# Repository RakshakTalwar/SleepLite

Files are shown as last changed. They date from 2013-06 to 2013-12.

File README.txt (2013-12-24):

This is an open collection of files for the SleepLite to allow the SleepLite to be fully open source and in public domain. 

You are free to use this any way you choose, non-commercial, commercial, or hobby use. 
Please give due credit. 

You can also purchase a kit with all the components, PCB, and preflashed microcontroller
here --> http://www.jameco.com/webapp/wcs/stores/servlet/ProductDisplay?productId=2184157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

Full tutorial with pictures, code, etc. is available 
here --> http://raptorbird.com/sleeplite-kit.php

I invested time and resources into making SleepLite fully open source and accessible, please support me by buying from Jameco or by contacting me for one directly at contact@raptorbird.com.

Written by Rakshak Talwar of RaptorBird.
Fully open source, hack your way to better sleep!

The software, information about hardware, hardware, and any other information here is without warranty. It is your responsibility only. 
This device has not been evaluated by the Food and Drug Administration and is not intended to diagnose, treat, cure or prevent any disease.
Caution: Do not use if you have heart problems or are prone to epileptic seizures.

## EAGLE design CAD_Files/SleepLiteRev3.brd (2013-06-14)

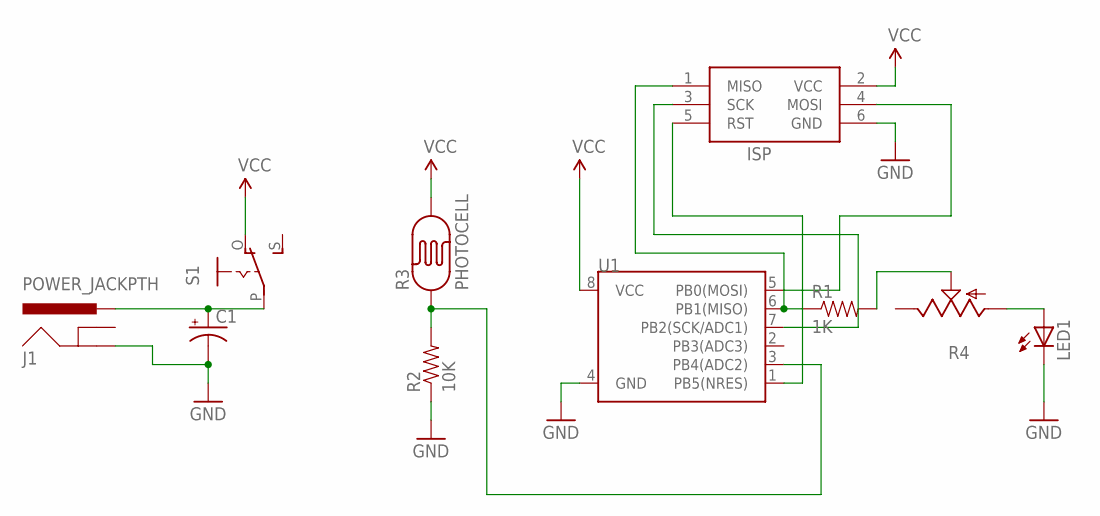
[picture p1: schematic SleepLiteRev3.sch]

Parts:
C1: CAP_POLPTH2; CPOL-RADIAL-10UF-25V
ISP: AVRISP-6; AVRISP
J1: POWER_JACKPTH; POWER_JACK_PTH
LED1: LED5MM
R1: 1K; AXIAL-0.4
R2: 10K; AXIAL-0.4
R3: PHOTOCELL; PHOTOCELL-KIT
R4: TRIM_US-B64Y; B64Y
S1: EG1218S; EG1218
U1: ATTINY13DIP; DIP08

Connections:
GND: C1.2 (-), ISP.6 (GND), J1.GND, LED1.K (C), R2.P$1 (1), U1.4 (GND)
unnamed: C1.1 (+), J1.PWR, S1.P
unnamed: R2.P$2 (2), R3.1, U1.3 (PB4(ADC2))
unnamed: ISP.1 (MISO), R1.P$1 (1), U1.6 (PB1(MISO))
unnamed: R1.P$2 (2), R4.S
unnamed: LED1.A, R4.A
unnamed: ISP.5 (RST), U1.1 (PB5(NRES))
unnamed: ISP.4 (MOSI), U1.5 (PB0(MOSI))
unnamed: ISP.3 (SCK), U1.7 (PB2(SCK/ADC1))
VCC: ISP.2 (VCC), R3.2, S1.O, U1.8 (VCC)

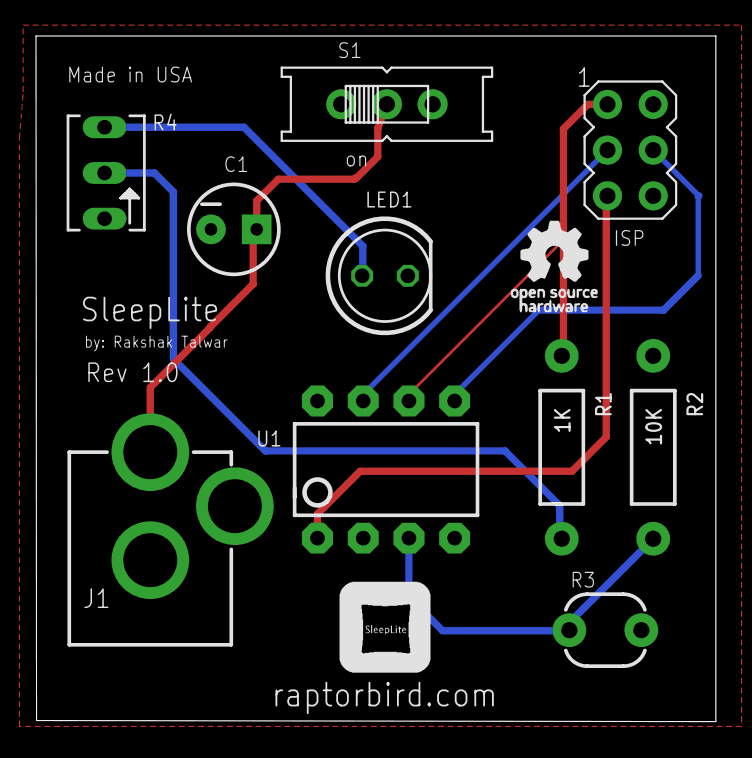
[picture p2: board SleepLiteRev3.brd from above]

Board: 2 copper layers, 37.8 x 38.1 mm, 10 parts (0 on the bottom side), 10 nets.

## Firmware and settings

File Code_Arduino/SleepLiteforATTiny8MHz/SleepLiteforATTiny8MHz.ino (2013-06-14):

/*
  Fades an LED at rate of human heart. Note: values are different as this
  is for ATTiny85 @ 8MHz.
  Instructions for ATTiny85 with Arduino Bootloader
  http://hlt.media.mit.edu/?p=1695
*/

#define lightSensor 2 //connect to pin 3 of ATTiny85 
#define led 1 //Connect to pin 6 of ATTiny85
int lightReading; //value of ambient light being received
float time = 1900.0; //time interval, sets frequency

void setup() 
{
  pinMode(led, OUTPUT); //Tells the ATTiny85 that the pin we're connecting the 
                         //LED to is an output
}

void loop() 
{
 
  lightReading = analogRead(lightSensor);
  
  if(lightReading <= 261)// if light level is low enough start SleepLite                                         
  {
    for(int i=0; i<=255; i++) //Gently fades in the LED
    {
    analogWrite(led, i);
    delayMicroseconds(time);
    }
    for(int i=255; i>=0; i--) //Gently fades out the LED
    {
    analogWrite(led, i); 
    delayMicroseconds(time);
    }
    if(time<(2600.0)) 
    time+=1.5; //rate at which the flashing slows (higher number = slower)
  }
  else //if too much ambient light keep SleepLite off 
    {
     analogWrite(led, 0); //turns off LED
     time = 1900.0; //resets frequency to 1Hz
     delay(1); //gives ATTiny85 a break
    }
}

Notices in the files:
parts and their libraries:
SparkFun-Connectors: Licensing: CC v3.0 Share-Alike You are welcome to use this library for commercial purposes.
